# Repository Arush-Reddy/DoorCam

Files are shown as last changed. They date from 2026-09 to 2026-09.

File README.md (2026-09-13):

# DoorCam: Edge-AI Smart Video Doorbell System









An autonomous, enterprise-grade smart video doorbell and surveillance system engineered from the silicon up. DoorCam pairs an **ESP32-CAM (AI-Thinker with OV3660 3MP sensor)** edge device with a multi-threaded Python cloud backend, local **128-dimensional deep metric facial recognition**, and an installable **Progressive Web App (PWA)** featuring **24/7 on-demand live cloud streaming**, **sub-2-second instant doorbell alerting**, and zero-refresh real-time synchronization.

> 🔒 **Private & Self-Hosted:** Designed for deployment on private cloud containers (Docker / Render) or home local servers with zero open inbound firewall ports.  
> Built as an end-to-end hardware, firmware, and software engineering system demonstrating embedded C++/FreeRTOS programming, low-latency socket networking, asynchronous machine learning pipelines, and modern web engineering.

---

## 📸 System Architecture

```mermaid
sequenceDiagram
    autonumber
    actor Visitor
    actor Owner as Homeowner (Phone / PWA)
    participant ESP as ESP32-CAM (Edge)
    participant Cloud as Cloud Server (Flask)
    participant AI as Face AI Worker (dlib)
    participant Push as Mobile Push (ntfy)

    Note over Owner,Cloud: Workflow A - 24/7 On-Demand Live Streaming
    Owner->>Cloud: Tap Watch Live Stream
    Cloud->>Cloud: Arm stream demand flag (60s safety timeout)
    ESP->>Cloud: Polls GET /api/stream_cmd (every 1.5s in standby)
    Cloud-->>ESP: Stream command active (true)
    ESP->>Cloud: Push live MJPEG frames (13-15 FPS)
    Cloud-->>Owner: Multiplex live feed to connected devices
    Owner->>Cloud: Tap Stop Stream
    Cloud-->>ESP: Demand cleared - ESP returns to standby

    Note over Visitor,Owner: Workflow B - Physical Doorbell Ring
    Visitor->>ESP: Press Doorbell Button (GPIO 14 to GND)
    ESP->>ESP: Hardware Debounce Filter (40ms) + Capture Photo
    ESP->>Cloud: POST /visitor with photo snapshot
    Note over Cloud: Immediate ACK under 10ms (Zero blocking)
    Cloud-->>Owner: Broadcast SSE event - Doorbell Ringing
    Owner-->>Owner: Play Web Audio Chime + Device Vibration
    Cloud-->>ESP: HTTP 200 OK - ESP begins 30s live stream
    Cloud->>AI: Dispatch snapshot to background worker
    AI->>AI: Compute HOG and 128D ResNet Embeddings
    AI-->>Cloud: Update database with recognized identity
    Cloud-->>Owner: Broadcast SSE event - Name Resolved (Arush)
    Cloud-->>Push: Dispatch mobile push notification with photo
```

---

## ⚡ Key Engineering Highlights & Innovations

### 1. 📹 24/7 On-Demand Live Cloud Streaming (Global 4G/5G/Wi-Fi)
- **Zero Open Ingress Ports**: The ESP32-CAM operates safely behind standard residential NAT without requiring port forwarding. It polls `GET /api/stream_cmd` every 1.5s while idling in a low-power, cool-running standby state.
- **Instant Cloud Spin-up**: When the homeowner taps **"Watch Live Stream"** in the app, the cloud activates a demand token. On the next poll cycle, the ESP32-CAM seamlessly transitions into high-throughput socket streaming, delivering smooth **13–15 FPS live MJPEG video**.
- **Bandwidth Safety Guard**: To prevent unexpected data exhaustion on cloud platforms (e.g. Render's 100 GB/month quota), each session includes an automatic **60-second countdown safety timeout**, or can be manually stopped with 1 tap.
- **In-Flight Frame Drain Guard**: Clicking "Stop" activates a 4.5-second frame drain barrier to cleanly ignore any delayed network packets and prevent UI stutter.

### 2. 🔔 Physical Doorbell Button Priority & Stream Interrupt
- **Hardware Circuitry**: A physical tactile pushbutton on **GPIO 14** configured with internal pull-up and a 40ms software debounce filter.
- **Ring Priority**:
  - **From Standby**: Captures an immediate HD visitor snapshot, pushes to `/visitor`, triggers an instant chime alert, and automatically extends into a 30-second live cloud stream so the owner can converse or monitor in real time.
  - **During Active Streaming**: An in-stream interrupt detects the button press on GPIO 14, immediately records the visitor event, and seamlessly refreshes the stream timer by +30 seconds without dropping frames.

### 3. ⚡ Sub-2-Second Instant Chime Alerting (Asynchronous Neural Inference)
- **The Challenge**: Running heavy convolutional face detection (`dlib` HOG + 128-dimensional ResNet-34 metric learning) synchronously on a CPU takes 300–600 ms. In cloud environments, waiting for inference before responding caused a 6–7 second delay between the visitor pressing the button and the homeowner's phone chiming.
- **The Solution**: The server immediately acknowledges `/visitor`, broadcasts a real-time event (`"Doorbell Ringing..."`) via Server-Sent Events (SSE), and dispatches inference to a background worker thread.
  - **Chime Latency**: The browser/phone chimes and vibrates within **~1.8–2.0 seconds** of the physical button press.
  - **Dynamic Name Resolution**: When the AI worker finishes identifying the face, it pushes an in-place `visitor_update` event that dynamically replaces the card title with the recognized name without re-triggering the chime audio.

### 4. 🧠 128-Dimensional Biometric Facial Recognition
- **Engine**: Powered by `dlib`'s state-of-the-art Deep Residual Network (ResNet-34) trained on millions of facial landmarks.
- **Metric Matching**: Generates a 128-float biometric vector per detected face and computes Euclidean distance against enrolled reference encodings in `face_db/encodings.pkl`.
- **Confidence Calibration**: Uses a strict classification threshold (`0.54`) to eliminate false positives, tagging unknown visitors as `Unknown Visitor` while instantly recognizing enrolled family members.

### 5. 🔄 Zero-Refresh Real-Time Live Sync & Mobile PWA
- **Hybrid SSE + High-Frequency Polling**: Combines persistent Server-Sent Events (`/api/events/stream`) for sub-millisecond push delivery with a 1.5-second `/api/live_state` heartbeat for rock-solid fault tolerance.
- **Web Audio API Synthesizer**: Generates a 2-tone melodic doorbell chime (*Ding* at 659.25 Hz E5 $\rightarrow$ *Dong* at 523.25 Hz C5) natively in browser memory without requiring external audio asset downloads.
- **Screen Wake Lock API**: Automatically invokes `navigator.wakeLock.request('screen')` during live stream viewing to keep the smartphone display awake while monitoring the doorstep.
- **Dynamic Frame Fallback**: If an MJPEG socket stalls due to cellular network switching, the frontend seamlessly falls back to 120ms single-frame memory polling (`/api/latest_frame`).

### 6. 🕒 Local Timezone Display & 1-Tap Feed Purge
- **Timezone Standardization**: Server records timestamps in Indian Standard Time (IST, UTC+5:30) using `datetime.timezone`. The frontend's dynamic `formatDisplayTime` parser automatically formats both legacy UTC and local timestamps into clean, human-readable strings (e.g. `Sep 13, 12:47:15 PM`).
- **Real-Time Feed Clearing (`POST /api/feed/clear`)**: A dedicated **`[ 🗑️ Clear ]`** button with confirmation prompt safely purges the SQLite `visits` database table. The server broadcasts a `feed_cleared` SSE event, instantly emptying the timeline and updating event counters across all open devices without requiring a browser reload.

### 7. 🛡️ PIR Motion Sensor Cloud Toggle
- Software-controlled toggle via `POST /api/pir/toggle` allows the homeowner to enable or disable HC-SR501 PIR thermal motion alerts directly from the UI, preventing nuisance notifications caused by pets, swaying trees, or passing street traffic.

---

## 📊 Benchmark & Performance Metrics

| Metric | Measured Value | Significance |
| :--- | :--- | :--- |
| **Physical Button Debounce** | **40 ms** | Clean active-LOW transition with zero false double-triggers |
| **Doorbell Trigger Latency** | **< 10 ms** | Server receives and broadcasts event before edge ACK completes |
| **End-to-End Phone Chime** | **~1.8 s** | Total time from physical press to phone chime & vibration over cloud |
| **On-Demand Stream Start** | **1.2 – 1.8 s** | Time from "Watch Live" tap to active video rendering |
| **Stream Frame Rate** | **13 – 15 FPS** | Fluid MJPEG video over standard residential Wi-Fi & 4G/5G |
| **Frame Bandwidth** | **~12 – 15 KB** | Optimized JPEG quality index (`12`) balancing clarity and throughput |
| **Face Recognition Time** | **~280 ms** | Multi-threaded background dlib ResNet-34 inference |
| **Mobile Push Notification** | **< 1.0 s** | Rich push with snapshot delivered to phone lock screen via `ntfy.sh` |
| **Camera Watchdog Recovery** | **~1.5 s** | Automated hardware reset (`ESP.restart()`) on consecutive frame drops |

---

## 🛠️ Hardware Bill of Materials (BOM) & Pinout

| Component | Specification | Function |
| :--- | :--- | :--- |
| **MCU** | ESP32-D0WD-V3 (AI-Thinker module, 4MB PSRAM) | Edge controller and camera driver |
| **Camera Sensor** | Omnivision OV3660 (3.0 Megapixel) | Optical image sensor with hardware ISP |
| **Programmer** | ESP32-CAM-MB Shield (or ESP32-S3 UART Bridge) | Serial flashing and 5V USB power regulation |
| **Motion Sensor** | HC-SR501 Passive Infrared (PIR) | Thermal motion detection |
| **Doorbell Button** | SPST Tactile Push Button | Physical visitor trigger (Active LOW) |
| **LEDs** | GPIO 4 (Flash, 1W) / GPIO 33 (Status, Red) | Night illumination and boot diagnostics |

### Edge Pin Mapping
```
ESP32-CAM Pin     Peripheral Connection
-----------------------------------------------------------
GPIO 14   ------> Doorbell Push Button (Active LOW with internal PULLUP)
GPIO 13   ------> PIR Motion Sensor OUT (PULLDOWN)
GPIO 4    ------> Onboard High-Power Flash LED
GPIO 33   ------> Onboard Red Status LED (Active LOW)
GPIO 32   ------> OV3660 Power Down (PWDN, Active HIGH)
GPIO 0    ------> Bootloader Flashing Mode (Short to GND to Flash)
5V / GND  ------> Regulated 5V 2A Power Source
```

---

## 📡 REST & Real-Time API Reference

| Endpoint | Method | Description |
| :--- | :--- | :--- |
| `/` | `GET` | CCTV Security Dashboard & Progressive Web App interface |
| `/video_feed` | `GET` | Live multi-client MJPEG video stream (`multipart/x-mixed-replace`) |
| `/api/latest_frame` | `GET` | Returns the single most recent JPEG frame from server memory |
| `/api/events/stream` | `GET` | Server-Sent Events (SSE) real-time event pipeline |
| `/api/live_state` | `GET` | Live system state (stream active, FPS, remaining time, latest visit, PIR state) |
| `/api/stream/start` | `POST` | Demands live cloud streaming for 60 seconds |
| `/api/stream/stop` | `POST` | Terminates active live streaming and returns camera to standby |
| `/api/stream_cmd` | `GET` | Polled by ESP32 edge device (`{"stream": true/false}`) |
| `/api/stream_push` | `POST` | Ingestion endpoint where ESP32 pushes live JPEG frames |
| `/visitor` | `POST` | Trigger endpoint called on button ring/motion with snapshot attachment |
| `/api/feed/clear` | `POST` | Purges all visitor log records and broadcasts `feed_cleared` event |
| `/api/pir/toggle` | `POST` | Toggles PIR motion sensor alert evaluation on/off |
| `/api/diagnostics` | `GET` | Health check endpoint reporting Python, OpenCV, dlib, and face models |

---

## 🚀 Deployment & Getting Started

### 1. Cloud Deployment (Render.com + Docker)
The project includes a production-ready `Dockerfile` pre-configured with Python 3.11, CMake, dlib, and `face_recognition`.
1. Fork or push this repository to your GitHub account.
2. Link your repository to **[Render.com](https://render.com/)** as a **Web Service**.
3. Set Environment: **Docker**.
4. Set optional environment variables in Render Dashboard:
   - `BASE_DIR=/app`
   - `NTFY_TOPIC=arush-doorcam-cctv` (or your custom topic name)
5. Render builds the container and serves your application at `https://<your-subdomain>.onrender.com`.

### 2. Local Development Setup
```bash
git clone https://github.com/Arush-Reddy/DoorCam.git
cd DoorCam

# Create and activate virtual environment
python -m venv venv
venv\Scripts\activate  # Windows
source venv/bin/activate  # Linux/macOS

# Install dependencies
pip install -r requirements.txt

# Run server locally
python doorbell_server.py
```

### 3. Enrolling Known Faces
1. Place portrait photos (`.jpg` or `.png`) of individuals inside `known_faces/`:
   ```text
   known_faces/
   ├── Arush.jpg
   └── Mom.jpg
   ```
2. Run the offline facial embedding generator:
   ```bash
   python face_db/encode_faces.py
   ```
   This generates `face_db/encodings.pkl`, which is loaded into server memory on startup.

### 4. Flashing Firmware to ESP32-CAM
1. Open `firmware/doorbell_cam/doorbell_cam.ino` in Arduino IDE.
2. Select Board: **AI Thinker ESP32-CAM** | Partition: **Huge APP (3MB No OTA/1MB SPIFFS)**.
3. Export compiled binary (`Ctrl + Alt + S` in Arduino IDE).
4. Short **IO0 to GND** on the ESP32-CAM and plug into USB (or mount on ESP32-CAM-MB shield).
5. Flash using the high-speed flasher:
   ```powershell
   python firmware/fast_flash.py
   ```
6. Disconnect **IO0 from GND** and press the **RST** button.

---

## 🔒 Security & Privacy Architecture

- **Self-Hosted Biometric Privacy**: Biometric facial recognition models and feature vectors execute entirely within your private container or local server. No private facial embeddings are ever uploaded to third-party proprietary clouds.
- **Zero Inbound NAT Openings**: Remote streaming operates via outbound long-polling and socket pushes—no risky port forwarding or firewall exceptions required.
- **Encrypted Global Ingress**: All mobile dashboard sessions, live MJPEG feeds, and push communications run over TLS 1.3 encryption (HTTPS/WSS).
- **Zero Subscription Fees**: Built entirely on self-hosted open-source software and open protocols.

---

## 📄 License

This project is licensed under the MIT License — see the [LICENSE](LICENSE) file for details.

---

## 👤 Author

**Arush Reddy**  
- **GitHub:** [@Arush-Reddy](https://github.com/Arush-Reddy)  
- **Project:** [DoorCam — Edge-AI Smart Video Doorbell System](https://github.com/Arush-Reddy/DoorCam)

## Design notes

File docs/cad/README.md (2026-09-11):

# 3D Printable DoorCam Enclosure (Robu.in Ready)

This directory contains the production-grade CAD designs, binary 3D printable `.stl` models, and visual renders for the **DoorCam Smart Doorbell Enclosure**.

Engineered specifically for the **5x7cm Double-Sided FR-4 Perfboard**, **AI-Thinker ESP32-CAM**, **HC-SR501 PIR sensor**, **16mm tactile push button**, and **Type-C 16-pin USB breakout**.

---

## 📦 Production STL Files for 3D Printing

Both files are pre-oriented flat on the build plate (`Z = 0`), watertight, manifold, and require **zero support material**:

| Part | File Link | Dimensions (mm) | Triangles | Format | Print Orientation |
| :--- | :--- | :--- | :--- | :--- | :--- |
| **Front Shell** | [`doorbell_front.stl`](doorbell_front.stl) | `58.8 x 124.8 x 13.0` | 3,808 | Binary STL | Flat face on bed |
| **Back Shell** | [`doorbell_back.stl`](doorbell_back.stl) | `58.8 x 124.8 x 15.8` | 3,104 | Binary STL | Wall face on bed |

*(ASCII versions are also preserved at [`doorbell_front_ascii.stl`](doorbell_front_ascii.stl) and [`doorbell_back_ascii.stl`](doorbell_back_ascii.stl) for text inspection).*

---

## 🎨 Visual 3D Renders

| Front Shell Interior | Back Wall Mount Interior | Full Assembled Unit |
| :---: | :---: | :---: |
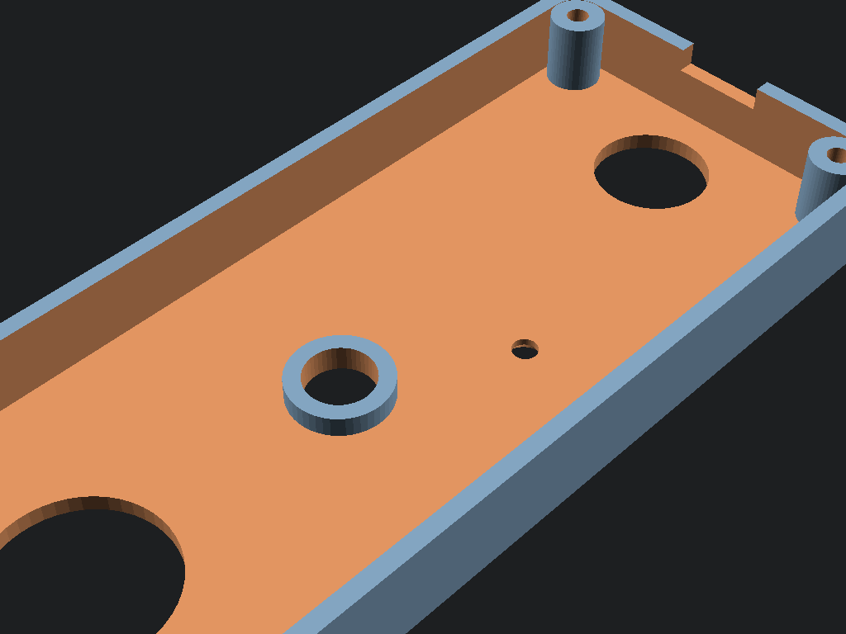
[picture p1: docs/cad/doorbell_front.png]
Front Shell
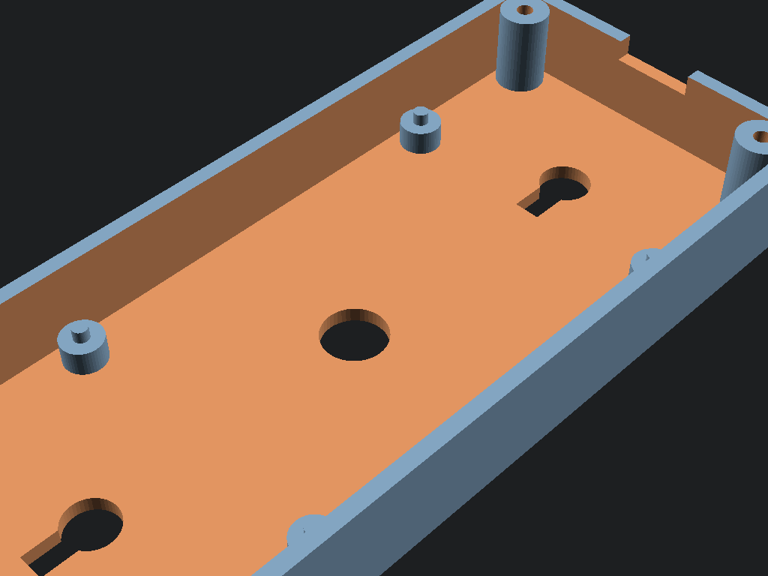
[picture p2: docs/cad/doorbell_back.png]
Back Shell
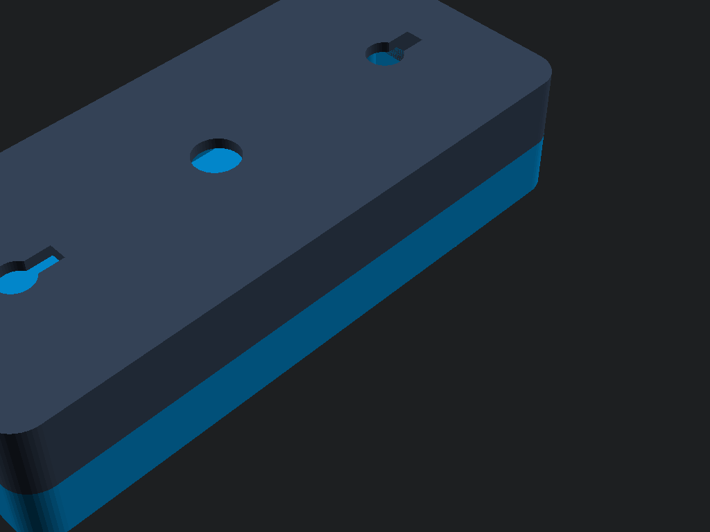
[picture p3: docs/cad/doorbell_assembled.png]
Assembled DoorCam
|  |  |  |

---

## 📐 Enclosure Technical Specifications

```
             Front Faceplate                            Side Cross-Section
     +------------------------------+                     +------------+
     |   [O] M3        [O] M3       |                     |            |
     |                              |                     |            |
     |          ( [CAM] )           | <-- 9.5mm Lens      |   FRONT    | 13.0 mm
     |                              |     Chamfer Bezel   |   SHELL    |
     |           ( PIR )            | <-- 23.5mm Dome     |            |
     |                              |     Cutout          +------------+ <-- Parting Line
     |                              |                     |            |
     |           [  O  ]            | <-- 16mm Button     |    BACK    | 15.8 mm
     |                              |     Aperture        |   SHELL    |
     |            ====              | <-- Type-C USB      | (Wall Mnt) |
     |   [O] M3        [O] M3       |                     |            |
     +------------------------------+                     +------------+
                 58.8 mm                                      28.8 mm
```

- **Outer Dimensions:** `58.8 mm (W) x 124.8 mm (L) x 28.8 mm (H)`
- **Internal Cavity:** `54.0 mm x 120.0 mm x 24.0 mm`
  - Perfectly accommodates standard 50mm x 70mm perfboard with 2mm perimeter clearance.
  - Accommodates stacked ESP32-CAM, female headers, 100µF capacitor, and wiring.
- **Wall Thickness:** `2.4 mm` (heavy-duty structural rigidity for outdoor environments).
- **Corner Fillets:** `6.5 mm` rounded radius.
- **Fasteners:** 4x M3 countersunk screws (`3.2 mm` clearance in front shell, `2.7 mm` self-tapping pilot holes in back shell).
- **Mounting:** 2x Wall screw keyholes (`8mm` head entry, `4.2mm` shank slot) + `10mm` center wire pass-through hole.
- **PCB Standoffs:** 4x built-in `4.0 mm` height support pillars in back shell.

---

## 🚀 How to Order on Robu.in 3D Printing Service

1. Visit [Robu.in Online 3D Printing Service](https://robu.in/product-category/3d-printing-services/).
2. Click **Instant Quote / Upload CAD Files**.
3. Upload both files:
   - `docs/cad/doorbell_front.stl`
   - `docs/cad/doorbell_back.stl`
4. Select the following print parameters:
   - **Technology:** **FDM (Fused Deposition Modeling)**
   - **Material:** **Black PETG** (Recommended for outdoor UV & weather resistance) or **PLA+**
   - **Infill:** **20% – 25%** (Gyroid or Grid pattern)
   - **Layer Height:** **0.20 mm** (Standard / Quality)
   - **Supports:** **None (Zero supports needed)**
5. Submit the order for delivery!

---

## 🛠️ Recompiling from Source

If you wish to modify dimensions:
1. Open [`doorbell_case.scad`](doorbell_case.scad) in OpenSCAD.
2. Edit dimensions in the header.
3. Run the automated build script:
   ```bash
   py -3.12 docs/cad/build_stls.py
   ```
   This compiles both STLs and updates preview renders automatically.

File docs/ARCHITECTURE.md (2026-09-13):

# System Architecture & Technical Deep Dive

This document details the hardware, firmware, and software engineering design decisions behind **DoorCam**, an open-source AI-powered smart video doorbell system.

---

## 1. System Block Diagram

```mermaid
graph TB
    subgraph EdgeDevice ["Edge Device: ESP32-CAM (AI Thinker + OV3660)"]
        OV[OV3660 3MP Sensor] -->|DMA / I2S Bus| CAM_BUF[2x Framebuffers in PSRAM]
        CAM_BUF -->|MJPEG Chunking| HTTP_SRV[esp_http_server Task: Port 81]
        BTN[Push Button GPIO 14] -->|Hardware Debounce| TRIG[Event Dispatcher]
        PIR[PIR HC-SR501 GPIO 13] -->|Active-High Interrupt| TRIG
        TRIG -->|HTTP POST ~5ms 0-byte| NET_OUT[WiFi Radio 2.4GHz]
    end

    subgraph HostServer ["Host Server: Python Flask Backend (Port 5000)"]
        NET_OUT -.->|HTTP POST /visitor| ROUTE_VIS[/visitor Endpoint]
        HTTP_SRV -.->|Persistent Single Socket| RELAY[CameraStreamRelay Worker Thread]
        RELAY -->|Latest Frame Buffer| RAM_BUF[(In-Memory JPEG Buffer)]
        
        ROUTE_VIS -->|Instant Snapshot Read| RAM_BUF
        ROUTE_VIS -->|Save to Disk| DISK[visitors/YYYY-MM-DD/]
        DISK -->|Image Array| FACE_AI[Face Recognition Engine: dlib / HOG]
        FACE_AI -->|Match Distance & ID| DB[(SQLite: visitors.db)]
        
        DB -->|Broadcast Visitor Event| SSE[Server-Sent Events: /api/events/stream]
        ROUTE_VIS -->|Dispatch Rich Alert| NTFY_CLIENT[ntfy.sh REST API]
    end

    subgraph Clients ["Client Ecosystem"]
        RAM_BUF -->|Deduplicated Stream| WEB_FEED[/video_feed: ~30 FPS]
        WEB_FEED --> PWA[Mobile / Desktop PWA Browser]
        SSE --> PWA
        NTFY_CLIENT --> MOBILE[Mobile Lock Screen Push Notifications]
    end
```

---

## 2. Firmware Architecture & Hardware Constraints

### A. DMA Buffer Allocation & Race Condition Avoidance
The ESP32-CAM utilizes an **OV3660 3-Megapixel CMOS sensor** communicating over a 10-line parallel interface (D0–D7, VSYNC, HREF, PCLK) using Direct Memory Access (DMA).

- **PSRAM Dual Buffering (`fb_count = 2`)**: The ESP32's 4MB external PSRAM is configured to allocate two framebuffers (`FRAMESIZE_VGA` at `640x480`).
- **Single-Consumer Guarantee**: To prevent catastrophic DMA starvation (where concurrent FreeRTOS tasks call `esp_camera_fb_get()` and exhaust buffers, locking up the I2S DMA FIFO), firmware enforces strict separation of concerns:
  - The `stream_handler` running on the `httpd` worker task is the **sole consumer** of `esp_camera_fb_get()`.
  - Doorbell push button and PIR sensor events **never** attempt camera capture on the edge device. Instead, they transmit a 0-byte trigger signal to the host server in ~5 ms.

### B. Self-Healing Camera Watchdog
Hardware sensors exposed to long jumper wires and electrical noise can experience SCCB/I2C bus drops or DMA timeouts. 
- Firmware implements consecutive-failure tracking in `stream_handler`:
  - Transient single-frame drops yield for 40 ms and retry without aborting the HTTP connection.
  - If 15 consecutive capture attempts fail, the firmware triggers an automated hardware reboot via `ESP.restart()`, bringing the camera back online within 1.5 seconds without requiring physical intervention.

---

## 3. Zero-Payload Event Triggering

Traditional IoT camera sketches attempt to capture high-resolution photos and upload multipart payloads (60–100 KB) when an event occurs. On single-radio 2.4 GHz ESP32 chips, doing this while simultaneously serving a video stream causes:
1. Wi-Fi packet drops and LwIP TCP buffer exhaustion.
2. Frame rate degradation to 0 FPS (freezing).
3. Simultaneous DMA buffer acquisition collisions.

### Zero-Payload Sequence Diagram
```mermaid
sequenceDiagram
    autonumber
    actor Visitor
    participant ESP as ESP32-CAM (Firmware)
    participant Relay as Python Stream Relay
    participant Host as Python /visitor Route
    participant Phone as Mobile Device (ntfy)

    Note over ESP,Relay: Continuous 25-30 FPS MJPEG Stream active on Port 81
    Visitor->>ESP: Presses Doorbell Button (GPIO 14 pulled LOW)
    ESP->>ESP: Hardware Debounce Filter (40 ms check)
    ESP->>Host: POST /visitor?trigger=BUTTON (Content-Length: 0)
    Note over ESP: Latency: ~5ms. Stream never pauses!
    Host->>Relay: Extract latest JPEG from memory buffer
    Host->>Host: Save JPEG to disk & run Face AI
    Host-->>Phone: Dispatch Push Notification with Photo Attachment
    Host-->>ESP: HTTP 200 OK
    ESP->>ESP: Blink onboard status LED
```

---

## 4. Software Backend & Stream Multiplexing

### A. CameraStreamRelay Architecture
The ESP32 `httpd` component is constrained to 4 concurrent sockets and single-threaded request handlers. Directly connecting multiple mobile phones and browser tabs to the camera locks up the device.

The Python server solves this using the **`CameraStreamRelay`** daemon:
- Maintains **exactly one** persistent HTTP connection to `http://<ESP32_IP>:81/`.
- Reads chunks from the HTTP stream, searches for JPEG boundary markers (`0xFF, 0xD8` for SOI and `0xFF, 0xD9` for EOI), and isolates complete frames into thread-safe memory.
- Protects the latest frame with a `threading.Lock()` and tracks the arrival timestamp `last_frame_time`.

### B. Frame Deduplication in `/video_feed`
Naive streaming relays yield the latest frame in a timed loop (e.g. every 40 ms). If the camera experiences a transient 100 ms Wi-Fi delay, the server sends duplicate frames, flooding client decoders.

DoorCam implements **timestamp-based frame deduplication**:
```python
last_sent_time = 0
while True:
    with camera_relay.lock:
        frame = camera_relay.latest_frame
        frame_time = camera_relay.last_frame_time
    if frame and frame_time != last_sent_time:
        last_sent_time = frame_time
        yield (b"--boundary\r\nContent-Type: image/jpeg\r\n\r\n" + frame + b"\r\n")
    time.sleep(0.01)
```
This guarantees clients receive only new, unique frames, minimizing client decode overhead and network utilization.

---

## 5. Facial Recognition Pipeline

```mermaid
flowchart LR
    A[Raw JPEG Frame] --> B[HOG Face Detection]
    B --> C[68 Face Landmarks]
    C --> D[128D Deep Metric Embedding]
    D --> E{Euclidean Distance <= 0.54?}
    E -- Yes --> F[Known Individual Label]
    E -- No --> G[Unknown Visitor]
```

1. **Detection**: Histogram of Oriented Gradients (HOG) algorithm identifies face bounding boxes.
2. **Alignment**: 68 facial landmarks are computed using dlib's shape predictor.
3. **Embedding**: A deep ResNet neural network maps the aligned face into a **128-dimensional hypersphere embedding**.
4. **Classification**: Vector distance between the input face embedding and the pre-computed known face database is calculated via Euclidean metric:
   $$d = \sqrt{\sum_{i=1}^{128} (x_i - y_i)^2}$$
5. **Threshold**: A calibrated distance threshold of `0.54` provides an optimal balance between false acceptance and false rejection on doorway perspectives.

---

## 6. Database Schema

DoorCam logs all visitor interactions to a lightweight SQLite database (`visitors.db`):

```sql
CREATE TABLE IF NOT EXISTS visits (
    id INTEGER PRIMARY KEY AUTOINCREMENT,
    timestamp DATETIME DEFAULT CURRENT_TIMESTAMP,
    name TEXT NOT NULL,
    photo_path TEXT NOT NULL,
    trigger_source TEXT NOT NULL,  -- 'BUTTON' or 'PIR'
    confidence REAL                -- Distance metric (lower is more confident)
);

CREATE INDEX IF NOT EXISTS idx_visits_timestamp ON visits(timestamp);
```

---

## 7. On-Demand Cloud Streaming & Bandwidth Safety Engine

To operate within cloud resource constraints (such as Render's 100 GB/month bandwidth limit) while preventing continuous heat generation on the ESP32-CAM, DoorCam employs an **on-demand signaling protocol**:

```mermaid
sequenceDiagram
    participant User as Mobile App / PWA
    participant Server as Flask Server (/api)
    participant Edge as ESP32-CAM

    Note over Edge,Server: Standby Mode: Low power, 0 FPS, polling /api/stream_cmd every 1.5s
    User->>Server: POST /api/stream/start {duration: 60}
    Server->>Server: Arm demand timer (expires in 60s)
    Edge->>Server: GET /api/stream_cmd
    Server-->>Edge: {"stream": true}
    Note over Edge: Edge spins up WiFiClient socket
    loop 13-15 FPS Live Stream
        Edge->>Server: POST /api/stream_push (JPEG frame binary)
        Server->>User: /video_feed (MJPEG multipart)
    end
    User->>Server: POST /api/stream/stop OR Timeout (60s)
    Server->>Server: Demand token cleared
    Edge->>Server: GET /api/stream_cmd
    Server-->>Edge: {"stream": false}
    Note over Edge: Edge terminates TCP push socket & returns to cool standby
```

### In-Flight Frame Drain Guard
When a user clicks **Stop Stream**, delayed network frames in transit over cellular data can arrive after the client has switched to snapshot view. The client and server enforce a 4.5-second frame drain barrier that suppresses stale frames, ensuring a clean freeze-frame snapshot state.

---

## 8. Asynchronous Biometric Inference & Sub-2s Chime Pipeline

Synchronous execution of deep convolutional neural networks (`dlib` HOG detection and ResNet-34 landmark embedding) introduces a 300–600 ms compute latency. Over WAN connections, this resulted in a 6–7 second delay between a physical button press and the homeowner's smartphone chiming.

### Decoupled Worker Thread Architecture
```mermaid
flowchart TD
    A[Button Pressed GPIO 14] -->|POST /visitor| B[Flask Request Handler]
    B -->|Broadcast Instant Alert| C[SSE: 'Doorbell Ringing...']
    C -->|Web Audio API| D[Phone Chimes in ~1.8s + Vibrates]
    B -->|HTTP 200 OK| E[ESP32 Begins 30s Stream]
    B -->|Enqueue Snapshot| F[Background AI Daemon Thread]
    F -->|dlib HOG & ResNet| G[Identify Face: 'Arush' / Unknown]
    G -->|Update DB Record| H[visitors.db]
    G -->|Broadcast In-Place Update| I[SSE: 'visitor_update']
    I -->|Smooth DOM Replacement| J[Card Name Updates Without Re-chiming]
```

This decoupled architecture guarantees **sub-2-second end-to-end chime alerts** while preserving 100% facial recognition accuracy.

---

## 9. Local Timezone Display & Real-Time Feed Purging

### Timezone Normalization
- Server instances (e.g. Render Linux containers running in UTC) record timestamps using `LOCAL_TIMEZONE = datetime.timezone(datetime.timedelta(hours=5, minutes=30))` (IST).
- The client-side `formatDisplayTime(rawTs)` engine automatically parses legacy UTC entries and current timestamps, formatting them cleanly as `Sep 13, 12:47:15 PM`.

### Real-Time Feed Clearing
- Triggering `POST /api/feed/clear` executes `DELETE FROM visits` on the SQLite database.
- The server broadcasts a `feed_cleared` event across the Server-Sent Events pipeline.
- All active browser tabs and mobile devices synchronously clear their DOM timelines, reset the event counter to `0 events`, and display the empty-state illustration without requiring a manual page refresh.

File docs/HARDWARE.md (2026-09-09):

# Hardware & Wiring Specifications

This guide covers component specifications, electrical schematics, pin mappings, and hardware flashing workflows for the **DoorCam** edge device.

---

## 1. Hardware Bill of Materials (BOM)

| Component | Part / Model | Purpose | Operating Voltage |
| :--- | :--- | :--- | :--- |
| **Edge Microcontroller** | ESP32-CAM (AI-Thinker) | Dual-core 240MHz MCU with 4MB External PSRAM & Wi-Fi | 5.0V input (3.3V internal) |
| **Image Sensor** | OmniVision OV3660 | 3.0 Megapixel CMOS sensor with 68° FoV & hardware ISP | 3.3V / 1.5V Core |
| **Motion Detector** | HC-SR501 | Passive Infrared (PIR) thermal motion sensor | 4.5V – 12V (5V rail) |
| **Doorbell Button** | 12mm Tactile Push Button | Physical visitor trigger switch | 3.3V Logic |
| **Status / Flash LEDs** | Onboard SMD LEDs | GPIO 4 (1W Warm Flash), GPIO 33 (Red Activity LED) | 3.3V Logic |
| **Power Supply** | Micro-USB 5V 2.0A Adapter | Clean, regulated DC power source | 5.0V ± 0.25V |

---

## 2. Complete Wiring Schematic

```
                          +-------------------+
                          |    ESP32-CAM      |
                          |                   |
       +5V Supply --------| 5V                |
       GND        --------| GND               |
                          |                   |
    [PIR Sensor]          |                   |
       VCC    <-----------| 5V                |
       GND    <-----------| GND               |
       OUT    ----------->| GPIO 13 (INPUT)   |
                          |                   |
    [Doorbell Button]     |                   |
       Terminal 1 ------->| GPIO 14 (PULLUP)  |
       Terminal 2 ------->| GND               |
                          |                   |
    [OV3660 Camera]       |                   |
       24-Pin FPC Cable ->| 24-Pin Camera Slot|
                          +-------------------+
```

### Pinout Rationale & Design Considerations:
- **GPIO 14 (Doorbell Push Button):** Configured as `INPUT_PULLUP`. In idle state, the internal pull-up resistor holds the pin HIGH (3.3V). Depressing the button shorts the pin directly to GND (Active LOW), triggering the 40ms debounce state machine.
- **GPIO 13 (PIR Sensor):** Configured as `INPUT_PULLDOWN`. When the HC-SR501 detects infrared radiation, its digital output goes HIGH (3.3V). The pull-down resistor eliminates floating gate noise when the sensor is uncoupled.
- **GPIO 32 (Camera Power Down / PWDN):** Used by the firmware watchdog to physically power-cycle the OV3660 CMOS sensor during bootup and failure recovery.
- **GPIO 4 & 33:** Onboard LEDs. GPIO 4 drives the flash transistor (Active HIGH); GPIO 33 drives the small red indicator LED (Active LOW).

---

## 3. Programming & Flashing Methods

### Method 1: Using the ESP32-CAM-MB Shield (Standard)
The **ESP32-CAM-MB** daughterboard plugs directly into the back header pins of the ESP32-CAM:
1. Mount the ESP32-CAM on the MB shield (ensure the antenna aligns with the shield cut-out).
2. Plug a standard Micro-USB cable into the MB shield port.
3. The onboard CH340 / CP2102 chip automatically toggles DTR and RTS lines to enter bootloader mode without manual jumpers.
4. Select board **AI Thinker ESP32-CAM** in Arduino IDE or run `python firmware/fast_flash.py`.

---

### Method 2: Using an ESP32-S3 as a Serial Bridge (No FTDI Needed)
If a dedicated USB-to-UART FTDI programmer is unavailable, an auxiliary **ESP32-S3 board** can be scripted as an ultra-fast hardware UART passthrough bridge.

#### Bridge Wiring:
```
  ESP32-S3 Bridge                ESP32-CAM (Target)
-----------------------------------------------------------
  5V             --------------> 5V
  GND            --------------> GND
  GPIO 18 (S3 RX) <------------- U0T (ESP32-CAM TX)
  GPIO 17 (S3 TX) --------------> U0R (ESP32-CAM RX)
  GND            --------------> IO0 (Short to GND for flashing)
```

#### Flashing Workflow via S3 Bridge:
1. Connect **IO0 to GND** on the ESP32-CAM.
2. Press the **RST** button on the ESP32-CAM to place its boot ROM in UART download mode.
3. Execute `python firmware/fast_flash.py`:
   ```bash
   python firmware/fast_flash.py
   ```
4. Once flashed, **disconnect IO0 from GND** and press the **RST** button to start normal operation.

---

## 4. Optical Sensor Tuning (OV3660)

The **Omnivision OV3660** 3MP CMOS sensor delivers significantly higher dynamic range and low-light sensitivity than the legacy OV2640.

The firmware applies the following hardware ISP corrections upon successful boot:
```c
sensor_t * s = esp_camera_sensor_get();
if (s && s->id.PID == OV3660_PID) {
    s->set_vflip(s, 1);        // Correct inverted optical lens mount
    s->set_hmirror(s, 0);      // Horizontal mirror off
    s->set_brightness(s, 1);   // Boost contrast in doorstep shadow conditions
    s->set_saturation(s, -1);  // Normalize aggressive color saturation
}
```

---

## 5. Electrical Stability & Brownout Protection

The ESP32 Wi-Fi radio draws brief current spikes up to **350–450 mA** during transmission. If powered via long USB cables or inadequate 500mA PC ports, the supply voltage can drop below 2.7V, triggering the ESP32 internal brownout detector.

**Mitigation Measures:**
1. **Software:** Brownout detector disabled in `setup()` via:
   ```c
   WRITE_PERI_REG(RTC_CNTL_BROWN_OUT_REG, 0);
   ```
2. **Hardware:** Use a dedicated 5V 2A USB wall adapter. A 100μF – 470μF electrolytic capacitor placed across the 5V and GND pins of the ESP32-CAM absorbs transient RF current spikes.

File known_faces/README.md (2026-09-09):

# Known Faces Directory

Place photos of known family members, friends, or yourself here.

### Guidelines:
1. **Naming**: The filename without extension will be used as the person's name.
   - Example: `arush.jpg` -> Name: **Arush**
   - Example: `dad.png` -> Name: **Dad**
   - Example: `uncle_bob.jpg` -> Name: **Uncle Bob**

2. **Photo Quality**:
   - Clear, well-lit, frontal face photo.
   - Only ONE person per photo.
   - Neutral expression or natural smile.

3. **After adding or updating photos**:
   Run:
   ```powershell
   python face_db/encode_faces.py
   ```
   This will update `face_db/encodings.pkl`.

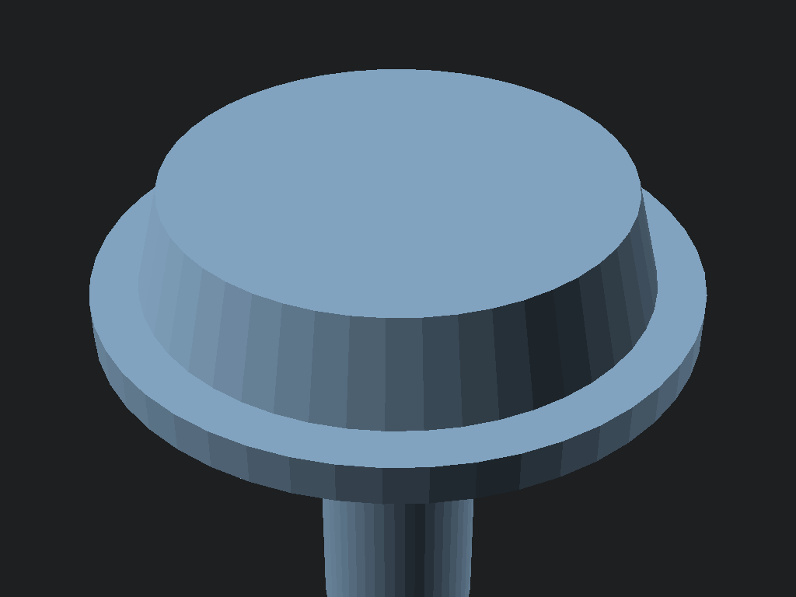
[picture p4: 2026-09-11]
docs/cad/doorbell_button.png

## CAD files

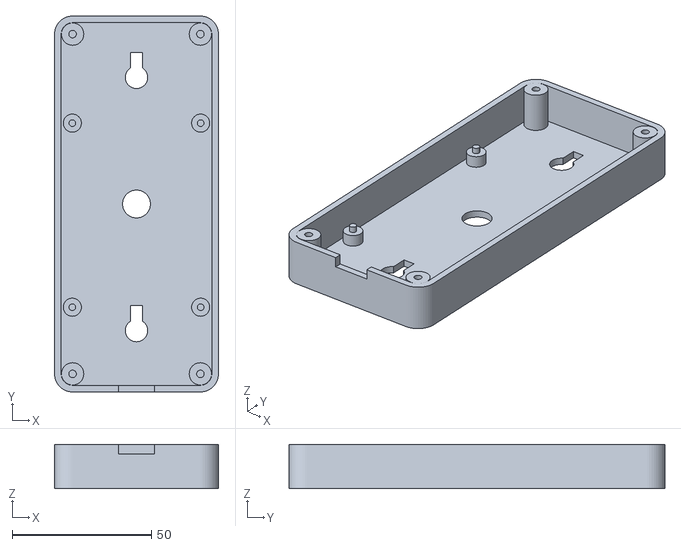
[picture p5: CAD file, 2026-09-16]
docs/cad/doorbell_back.stl
58.8 x 134.8 x 15.8

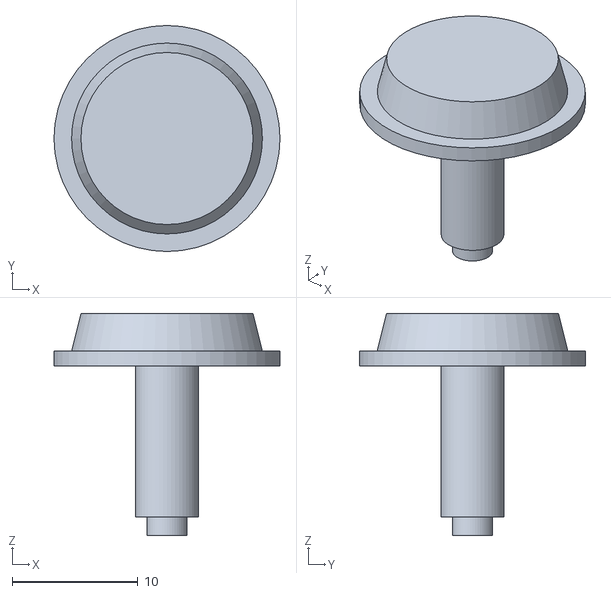
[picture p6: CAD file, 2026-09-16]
docs/cad/doorbell_button_ascii.stl
18.0 x 18.0 x 17.7

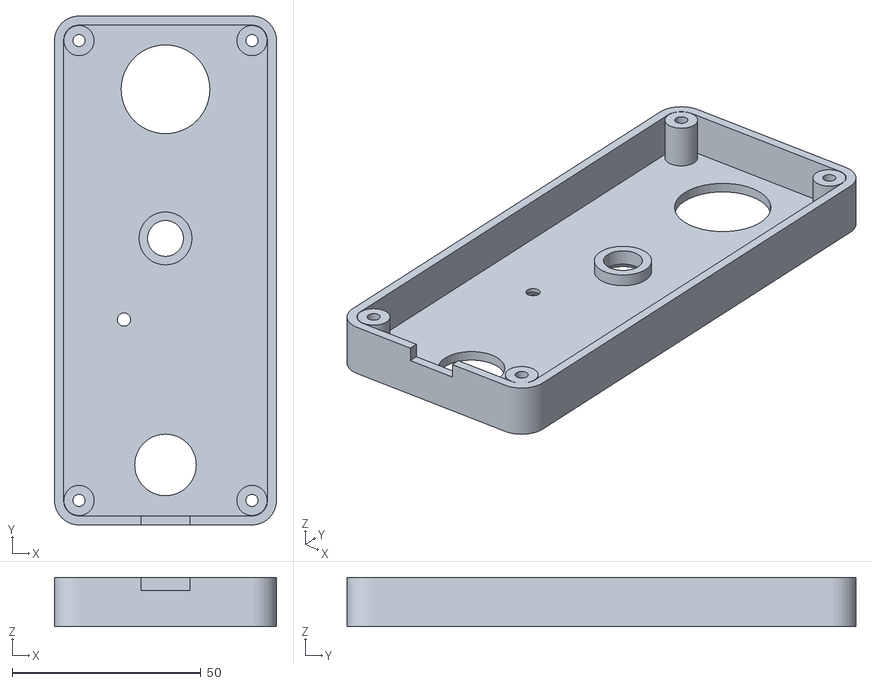
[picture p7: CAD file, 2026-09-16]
docs/cad/doorbell_front_ascii.stl
58.8 x 134.8 x 13.0

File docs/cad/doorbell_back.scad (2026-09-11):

// DoorCam Back Shell (Robu 3D Print Ready)
// Flat on build plate (Z=0, zero supports needed)
use <doorbell_case.scad>

$fn = 48;
back_shell();

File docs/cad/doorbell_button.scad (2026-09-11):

// DoorCam 16mm Tactile Button Plunger Cap
// Fits the 16mm front shell aperture and presses an internal 6x6mm tactile switch
$fn = 48;

cap_d     = 15.2;   // Outer button cap diameter (smooth slip fit in 16mm hole)
cap_h     = 3.0;    // Visible button face thickness
flange_d  = 18.0;   // Retaining flange (prevents button from falling out of front)
flange_h  = 1.2;    // Flange thickness
stem_d    = 5.0;    // Stem diameter pressing against the 6x6 tactile button
stem_len  = 12.0;   // Length extending to reach the PCB switch
nub_d     = 3.2;    // Actuator tip
nub_h     = 1.5;

union() {
    // 1. Chamfered tactile face (pokes through front hole)
    translate([0, 0, flange_h])
        cylinder(d1=cap_d, d2=cap_d - 1.5, h=cap_h);

    // 2. Retaining flange (rests inside the case against front wall)
    cylinder(d=flange_d, h=flange_h);

    // 3. Central plunger stem extending down to the 6x6mm switch
    translate([0, 0, -stem_len])
        cylinder(d=stem_d, h=stem_len);

    // 4. Contact nub that centers onto the tactile button
    translate([0, 0, -stem_len - nub_h])
        cylinder(d=nub_d, h=nub_h);
}

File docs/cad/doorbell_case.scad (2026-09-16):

// ====================================================================
// DoorCam v1.0 - Production 3D Printable Smart Doorbell Enclosure
// Precision engineered for: 
//   - 5x7cm Perfboard (50mm x 70mm)
//   - AI-Thinker ESP32-CAM (OV3660 / OV2640)
//   - HC-SR501 PIR Motion Sensor (23mm Fresnel dome)
//   - 6x6mm Tactile Button (via 3D Plunger) OR 16mm Panel Button
//   - Type-C 16-Pin USB Breakout Board
// Fully optimized for Robu.in / JLCPCB / Local 3D Print Services
// ====================================================================

$fn = 48; // Ultra-smooth curves for production quality

// --- PART SELECTOR ---
PART = "assembled"; // ["front", "back", "button", "assembled"]

// --- CORE DIMENSIONS (mm) ---
wall_thick   = 2.4;     // Sturdy outdoor wall thickness
inner_w      = 54.0;    // 50.0mm perfboard + 2mm margin per side
inner_l      = 130.0;   // 70mm perfboard + 34mm PIR cavity + 26mm button bay
inner_h      = 24.0;    // Internal cavity height for full component stack
fillet_r     = 6.5;     // Smooth ergonomic rounded outer corners

outer_w      = inner_w + wall_thick * 2; // 58.8 mm
outer_l      = inner_l + wall_thick * 2; // 134.8 mm (~13.5 cm)

split_z      = 13.0;    // Front shell height
back_depth   = inner_h - (split_z - wall_thick) + wall_thick; // 15.8 mm (Total height = 28.8 mm)

// --- SENSOR & APERTURE POSITIONS (from bottom inner wall) ---
// Based on exact eye-level physical ruler measurements:
pcb_offset_y = 26.0;    // Perfboard bottom edge rests at 26.0mm from bottom inner wall
cam_lens_d   = 9.5;     // OV3660 lens barrel diameter
cam_lens_y   = pcb_offset_y + 47.5; // 73.5 mm (EXACT match to user's 4.75cm physical eye measurement!)
pir_d        = 23.5;    // HC-SR501 Fresnel dome diameter
pir_y        = 113.0;   // Centered in top 34mm cavity (5.25mm clearance each side)
btn_d        = 16.3;    // 16.3mm slip-fit for M16 panel button (R13-507)
btn_y        = 13.5;    // Centered in bottom bay (5.35mm to wall, 4.35mm to PCB)
flash_led_x  = -11.0;   // Flash LED X offset from center (-11.0 = bottom-right when viewed from front face)
flash_led_y  = pcb_offset_y + 26.0; // 52.0 mm (EXACT match to user's 2.6cm physical eye measurement!)
flash_led_d  = 3.5;     // 3.5mm aperture for wide-angle flashlight illumination
usbc_w       = 13.0;    // USB-C clearance width
usbc_h       = 7.0;     // USB-C clearance height

screw_inset  = 6.5;     // Corner screw center from outer edge
boss_od      = 8.0;     // Screw boss outer diameter

// --- HELPER: ROUNDED BOX ---
module rounded_box(w, l, h, r) {
    hull() {
        translate([r, r, 0]) cylinder(r=r, h=h);
        translate([w-r, r, 0]) cylinder(r=r, h=h);
        translate([r, l-r, 0]) cylinder(r=r, h=h);
        translate([w-r, l-r, 0]) cylinder(r=r, h=h);
    }
}

// ====================================================================
// 1. FRONT SHELL (Outer face flat on bed at Z=0, zero supports needed!)
// ====================================================================
module front_shell() {
    difference() {
        // --- 1. SOLID POSITIVES ---
        union() {
            // Hollow Body Tray (Outer box minus cavity)
            difference() {
                rounded_box(outer_w, outer_l, split_z, fillet_r);
                translate([wall_thick, wall_thick, wall_thick])
                    rounded_box(inner_w, inner_l, split_z + 1, max(1, fillet_r - wall_thick));
            }

            // 4 Corner Screw Bosses (solid columns inside the tray)
            for (pos = [
                [screw_inset, screw_inset],
                [outer_w - screw_inset, screw_inset],
                [screw_inset, outer_l - screw_inset],
                [outer_w - screw_inset, outer_l - screw_inset]
            ]) {
                translate([pos[0], pos[1], wall_thick])
                    cylinder(d=boss_od, h=split_z - wall_thick);
            }

            // Camera Lens Rear Positioning Collar
            translate([outer_w/2, wall_thick + cam_lens_y, wall_thick])
                cylinder(d=cam_lens_d + 4.5, h=3.0);
        }

        // --- 2. NEGATIVE CUTOUTS ---

        // 1. Camera Lens Aperture
        translate([outer_w/2, wall_thick + cam_lens_y, -1])
            cylinder(d=cam_lens_d, h=wall_thick + 5.0);

        // 2. Protective Lens Chamfer Bezel (Angled sun/rain hood)
        translate([outer_w/2, wall_thick + cam_lens_y, -0.1])
            cylinder(d1=cam_lens_d + 3.6, d2=cam_lens_d, h=1.8);

        // 3. Status / Flash LED Light-pipe (3.5mm hole with wide-beam bezel)
        translate([outer_w/2 + flash_led_x, wall_thick + flash_led_y, -1])
            cylinder(d=flash_led_d, h=wall_thick + 2.0);
        translate([outer_w/2 + flash_led_x, wall_thick + flash_led_y, -0.1])
            cylinder(d1=flash_led_d + 2.0, d2=flash_led_d, h=1.5);

        // 4. HC-SR501 PIR Dome Aperture (23.5mm)
        translate([outer_w/2, wall_thick + pir_y, -1])
            cylinder(d=pir_d, h=wall_thick + 2.0);

        // 5. Doorbell Push Button Hole (16mm through outer wall & guide sleeve)
        translate([outer_w/2, wall_thick + btn_y, -1])
            cylinder(d=btn_d, h=wall_thick + 6.0);

        // 6. USB-C Port Notch (Top half at split line)
        translate([outer_w/2 - usbc_w/2, -1, split_z - usbc_h/2])
            cube([usbc_w, wall_thick + 2, usbc_h + 1]);

        // 7. Corner Screws (M3 Clearance = 3.2mm through outer wall & boss)
        for (pos = [
            [screw_inset, screw_inset],
            [outer_w - screw_inset, screw_inset],
            [screw_inset, outer_l - screw_inset],
            [outer_w - screw_inset, outer_l - screw_inset]
        ]) {
            // 3.2mm Clearance Hole
            translate([pos[0], pos[1], -1])
                cylinder(d=3.2, h=split_z + 2);

            // M3 Countersink Head on outer face (90-degree standard cone)
            translate([pos[0], pos[1], -0.1])
                cylinder(d1=6.4, d2=3.2, h=1.8);
        }
    }
}

// ====================================================================
// 2. BACK SHELL (Mounting face flat on bed at Z=0, zero supports needed!)
// ====================================================================
module back_shell() {
    difference() {
        // --- 1. SOLID POSITIVES ---
        union() {
            // Hollow Body Tray (Outer box minus cavity)
            difference() {
                rounded_box(outer_w, outer_l, back_depth, fillet_r);
                translate([wall_thick, wall_thick, wall_thick])
                    rounded_box(inner_w, inner_l, back_depth + 1, max(1, fillet_r - wall_thick));
            }

            // 4 Corner Screw Bosses (with M3 pilot holes)
            for (pos = [
                [screw_inset, screw_inset],
                [outer_w - screw_inset, screw_inset],
                [screw_inset, outer_l - screw_inset],
                [outer_w - screw_inset, outer_l - screw_inset]
            ]) {
                translate([pos[0], pos[1], wall_thick])
                    cylinder(d=boss_od, h=back_depth - wall_thick);
            }

            // 4 Perfboard Support Standoffs (4mm height, supports 50x70mm board)
            // Exactly aligned with user's physical measurement: 46.0mm (W) x 66.0mm (H)
            pcb_standoff_h = 4.0;
            hole_dx = 46.0;
            hole_dy = 66.0;
            board_margin_x = (50.0 - hole_dx) / 2; // 2.0mm
            board_margin_y = (70.0 - hole_dy) / 2; // 2.0mm
            board_start_x  = outer_w / 2 - 25.0;    // centered 50mm board
            for (p = [
                [board_start_x + board_margin_x, wall_thick + pcb_offset_y + board_margin_y],
                [board_start_x + 50.0 - board_margin_x, wall_thick + pcb_offset_y + board_margin_y],
                [board_start_x + board_margin_x, wall_thick + pcb_offset_y + 70.0 - board_margin_y],
                [board_start_x + 50.0 - board_margin_x, wall_thick + pcb_offset_y + 70.0 - board_margin_y]
            ]) {
                translate([p[0], p[1], wall_thick]) {
                    cylinder(d=6.5, h=pcb_standoff_h);
                    // 2.4mm locating pin (drops right into perfboard M3 corner holes for instant alignment!)
                    cylinder(d=2.4, h=pcb_standoff_h + 2.0);
                }
            }
        }

        // --- 2. NEGATIVE CUTOUTS ---

        // 1. USB-C Port Notch (Bottom half at split line)
        translate([outer_w/2 - usbc_w/2, -1, back_depth - usbc_h/2])
            cube([usbc_w, wall_thick + 2, usbc_h + 1]);

        // 2. Wall Mounting Keyhole Top
        translate([outer_w/2, outer_l - 22.0, -1]) {
            cylinder(d=8.0, h=wall_thick + 2); // Head entry
            translate([-2.1, 0, 0]) cube([4.2, 9.0, wall_thick + 2]); // Shank slot
        }

        // 3. Wall Mounting Keyhole Bottom
        translate([outer_w/2, 22.0, -1]) {
            cylinder(d=8.0, h=wall_thick + 2);
            translate([-2.1, 0, 0]) cube([4.2, 9.0, wall_thick + 2]);
        }
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

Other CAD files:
docs/cad/doorbell_back_ascii.stl
docs/cad/doorbell_front.stl
docs/cad/doorbell_button.stl
docs/cad/doorbell_front.scad

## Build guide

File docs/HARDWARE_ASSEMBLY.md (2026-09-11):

# DoorCam Hardware Assembly & Soldering Blueprint

This document provides the complete, hole-by-hole assembly guide for soldering the **DoorCam Smart Video Doorbell** onto a standard **5cm x 7cm Double-Sided FR-4 Perfboard (Zero PCB)**.

---

## Components Checklist

| Component | Quantity | Position on Board |
|---|:---:|---|
| **5x7 cm FR-4 Double-Sided Perfboard** | 1 | Main substrate |
| **40-pin Female Header Strip** | Snip two 1x8 strips | Center-top (ESP32-CAM socket) |
| **Type-C 16-Pin Breakout Board** | 1 | Bottom edge (facing outward) |
| **SPST Tactile Push Button** | 1 | Bottom center / offset |
| **3-Pin Male Header Strip** | Snip 1x3 pins | Top/side edge (PIR harness connector) |
| **100uF 35V Electrolytic Capacitor** | 1 | Near ESP32-CAM 5V/GND pins |
| **100nF (104) Ceramic Capacitor** | 1 | In parallel with 100uF cap across 5V/GND |
| **24 AWG Hookup Wire** | A few scraps | Underside point-to-point bridging |

---

## Top-Side Component Layout

A 5x7 cm perfboard has **18 holes horizontally** and **28 holes vertically** (standard 2.54mm pitch).

`
   +---------------------------------------------------+
   |  [O] M3 Mounting Hole         M3 Mounting Hole [O]|  <-- TOP
   |                                                   |
   |              [PIR HEADER: VCC OUT GND]             |  <-- Row 4
   |                     (1x3 Male)                    |
   |                                                   |
   |      [ 1x8 Female ]         [ 1x8 Female ]        |  <-- Rows 7-14
   |      (ESP32-CAM Left)       (ESP32-CAM Right)     |      (Spaced 8 holes apart)
   |       1. 5V                  1. GND               |
   |       2. GND                 2. IO0               |
   |       3. IO12                3. IO16              |
   |       4. IO13 (PIR)          4. IO14 (Button)     |
   |       5. IO15                5. GND               |
   |       6. IO2                 6. 3V3               |
   |       7. IO4 (Flash)         7. U0R               |
   |       8. GND                 8. U0T               |
   |                                                   |
   |        [CAP: 100uF]  [CAP: 100nF]                 |  <-- Rows 16-17
   |                                                   |
   |                   [PUSH BUTTON]                   |  <-- Rows 19-21
   |                   (4-pin Tactile)                 |
   |                                                   |
   |             [TYPE-C BREAKOUT BOARD]               |  <-- Rows 24-27
   |                [ USB-C PORT v ]                   |  <-- BOTTOM EDGE
   |  [O] M3 Mounting Hole         M3 Mounting Hole [O]|
   +---------------------------------------------------+
`

---

## Circuit Schematic & Wiring Connections

### 1. Power Distribution (5V & GND Rails)
`
[Type-C Breakout]
   VBUS (5V) ───────┬───────────────────> ESP32-CAM Pin 1 (5V)
                    ├───────────────────> PIR Sensor Header Pin 1 (VCC)
                    ├──────(+) [100uF]
                    └───────┤  [100nF]
   GND      ────────┬──────(-) [100uF]
                    ├───────┤  [100nF]
                    ├───────────────────> ESP32-CAM Pin 2 (GND)
                    ├───────────────────> PIR Sensor Header Pin 3 (GND)
                    └───────────────────> Push Button Leg 1 (GND)
`

### 2. Sensor & Button Signal Wiring
`
[PIR Motion Sensor]
   OUT (Signal) ────────────────────────> ESP32-CAM Pin 4 (GPIO 13)

[Doorbell Push Button]
   Button Leg 1 ────────────────────────> Ground (GND)
   Button Leg 2 ────────────────────────> ESP32-CAM Pin 12 (GPIO 14)
   (Note: GPIO 14 has internal software PULLUP enabled in firmware; no external resistor needed!)
`

### 3. Capacitor Orientation (Crucial!)
* **100uF Electrolytic Capacitor (Black cylinder):**
  * **Longer Leg = POSITIVE (+)** -> Connect to **5V Rail**.
  * **Shorter Leg / White Stripe = NEGATIVE (-)** -> Connect to **GND Rail**.
* **100nF Ceramic Capacitor (Yellow/orange bead 104):**
  * Non-polar. Solder directly across 5V and GND right next to the 100uF capacitor.

---

## Step-by-Step Soldering Sequence

Follow this order for the cleanest assembly:

### Step 1: Prepare the Sockets
1. Take your 40-pin female header strip.
2. Carefully snip off **two 8-pin pieces** using flush cutters.
3. Clean up the edges so they sit flush.

### Step 2: Solder the ESP32-CAM Socket
1. Push the two 8-pin female headers into the perfboard spaced **8 holes apart** (20.32 mm from center-to-center).
2. Insert your ESP32-CAM into the female headers temporarily **before soldering**. This keeps both rows perfectly parallel while you solder the pins on the underside!
3. Solder the corner pins first, verify alignment, then solder all remaining pins.
4. Unplug the ESP32-CAM and set it aside safely.

### Step 3: Solder the Power Capacitors
1. Place the 100nF ceramic capacitor and 100uF electrolytic capacitor close to the ESP32-CAM 5V and GND pins.
2. Double-check electrolytic polarity: **White stripe with minus signs (-) must go to GND!**

### Step 4: Solder the Push Button & PIR Header
1. Push the 4-pin tactile button into the board and bend its legs slightly on the back so it stays in place. Solder all 4 pins.
2. Snip a **3-pin piece** from your male header strip and solder it near the top of the board for the PIR sensor wire harness.

### Step 5: Solder the USB-C Breakout Board
1. Place the Type-C breakout board along the bottom edge so the metal USB-C port faces outward past the edge of the perfboard.
2. Solder male header pins or short solid-core wires from the VBUS and GND pads into the perfboard power rails.

### Step 6: Underside Point-to-Point Wiring
1. Route short insulated wire bridges (or create clean solder bridges) connecting:
   - **5V Rail:** Type-C VBUS -> Capacitors (+) -> ESP32 Pin 1 (5V) -> PIR Pin 1 (VCC).
   - **GND Rail:** Type-C GND -> Capacitors (-) -> ESP32 Pin 2 (GND) -> PIR Pin 3 (GND) -> Button Leg 1.
   - **PIR Signal:** PIR Pin 2 (OUT) -> ESP32 Pin 4 (GPIO 13).
   - **Button Signal:** Button Leg 2 -> ESP32 Pin 12 (GPIO 14).

---

## Pre-Power Safety Checklist (Do NOT Skip!)

Before plugging in your USB-C cable for the first time:

1. **Multimeter Continuity Check:**
   - Set multimeter to Continuity / Beep mode.
   - Place one probe on **5V** and the other on **GND**.
   - **It must NOT beep!** (If it beeps, you have a solder bridge short-circuit. Inspect and clean the underside pads).
2. **Polarity Check:**
   - Verify the 100uF capacitor white stripe is on Ground.
3. **Power Test (Without ESP32-CAM):**
   - Plug in your USB-C cable **without the ESP32-CAM installed**.
   - Measure DC Voltage with multimeter across the female header pins:
     - Pin 1 (5V) to Pin 2 (GND) should read **+4.9V to +5.2V**.
4. **Final Assembly:**
   - Unplug USB.
   - Seat the ESP32-CAM firmly into its sockets.
   - Plug in USB -> Watch the red status LED blink and verify live stream on your dashboard!

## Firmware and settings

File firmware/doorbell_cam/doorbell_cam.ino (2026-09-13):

/*
 * Smart Video Doorbell - ESP32-CAM Firmware
 * Optimized for: ESP32-CAM (AI Thinker) with OV3660 Sensor & MB Programmer Shield
 * 
 * Hardware Connections:
 *   - PIR Motion Sensor (HC-SR501) OUT -> GPIO 13
 *   - Doorbell Push Button -> GPIO 14 (Connect other side of button to GND)
 *   - Flash LED -> GPIO 4 (Onboard high-power white LED)
 *   - Status LED -> GPIO 33 (Onboard small red LED, Active LOW)
 * 
 * Arduino IDE Settings:
 *   - Board: "AI Thinker ESP32-CAM"
 *   - CPU Frequency: 240MHz (WiFi/BT)
 *   - Flash Frequency: 80MHz
 *   - Flash Mode: QIO
 *   - Partition Scheme: "Huge APP (3MB No OTA/1MB SPIFFS)"
 *   - Upload Speed: 115200 or 921600
 */

#include "esp_camera.h"
#include <WiFi.h>
#include <WiFiClient.h>
#include <WiFiClientSecure.h>
#include "esp_http_server.h"
#include "soc/soc.h"
#include "soc/rtc_cntl_reg.h"

// Forward declarations
bool triggerDoorbell(const char* triggerType);
void streamCloudBurst(int durationSeconds);
bool checkCloudStreamCommand();

// ==========================================
// 1. NETWORK & SERVER CONFIGURATION
// ==========================================
#if __has_include("credentials.h")
  #include "credentials.h"
#else
  const char* ssid = "YOUR_WIFI_SSID";
  const char* password = "YOUR_WIFI_PASSWORD";
  const char* serverHost = "192.168.0.4"; // Local IP of server running doorbell_server.py
  const int serverPort = 5000;
#endif

#define ENABLE_PIR false  // Disabled temporarily to prevent false motion triggers
const char* serverPath = "/visitor";

// ==========================================
// 2. PIN DEFINITIONS (AI-THINKER PINOUT)
// ==========================================
#define PWDN_GPIO_NUM     32
#define RESET_GPIO_NUM    -1
#define XCLK_GPIO_NUM      0
#define SIOD_GPIO_NUM     26
#define SIOC_GPIO_NUM     27

#define Y9_GPIO_NUM       35
#define Y8_GPIO_NUM       34
#define Y7_GPIO_NUM       39
#define Y6_GPIO_NUM       36
#define Y5_GPIO_NUM       21
#define Y4_GPIO_NUM       19
#define Y3_GPIO_NUM       18
#define Y2_GPIO_NUM        5
#define VSYNC_GPIO_NUM    25
#define HREF_GPIO_NUM     23
#define PCLK_GPIO_NUM     22

// Peripherals
#define PIR_PIN           13     // HC-SR501 PIR Output (PULLDOWN prevents floating triggers)
#define BUTTON_PIN        14     // Doorbell Push Button (Active LOW with internal PULLUP)
#define FLASH_LED_PIN      4     // Onboard Flash LED (Active HIGH)
#define STATUS_LED_PIN    33     // Onboard Red LED (Active LOW)

// Hardware Button Interrupt State
volatile bool g_buttonTriggered = false;
unsigned long g_lastButtonInterruptTime = 0;

void IRAM_ATTR button_isr() {
  unsigned long now = millis();
  if (now - g_lastButtonInterruptTime > 300) {
    g_buttonTriggered = true;
    g_lastButtonInterruptTime = now;
  }
}

// Cooldown between captures to avoid spamming the server
const unsigned long CAPTURE_COOLDOWN_MS = 6000;
unsigned long lastCaptureTime = 0;
bool cameraInitialized = false;

// Global camera configuration structure
camera_config_t s_camera_config = {};

// HTTP server instance for live streaming
httpd_handle_t stream_httpd = NULL;

#define PART_BOUNDARY "123456789000000000000987654321"
static const char* _STREAM_CONTENT_TYPE = "multipart/x-mixed-replace;boundary=" PART_BOUNDARY;
static const char* _STREAM_BOUNDARY = "\r\n--" PART_BOUNDARY "\r\n";
static const char* _STREAM_PART = "Content-Type: image/jpeg\r\nContent-Length: %u\r\n\r\n";

// Stream handler for live video preview
static esp_err_t stream_handler(httpd_req_t *req) {
  camera_fb_t * fb = NULL;
  esp_err_t res = ESP_OK;
  size_t _jpg_buf_len = 0;
  uint8_t * _jpg_buf = NULL;
  char part_buf[64];

  res = httpd_resp_set_type(req, _STREAM_CONTENT_TYPE);
  if (res != ESP_OK) return res;

  httpd_resp_set_hdr(req, "Access-Control-Allow-Origin", "*");

  int consecutive_failures = 0;

  while (true) {
    fb = esp_camera_fb_get();
    if (!fb) {
      Serial.println("[CAM] Stream frame buffer grab failed");
      consecutive_failures++;
      if (consecutive_failures >= 15) {
        Serial.println("[CAM CRITICAL] 15 consecutive capture failures! Auto-restarting ESP32...");
        delay(100);
        ESP.restart();
      }
      delay(40);
      continue;
    }
    consecutive_failures = 0;

    _jpg_buf_len = fb->len;
    _jpg_buf = fb->buf;

    size_t hlen = snprintf((char *)part_buf, 64, _STREAM_PART, _jpg_buf_len);
    res = httpd_resp_send_chunk(req, (const char *)part_buf, hlen);
    if (res == ESP_OK) {
      res = httpd_resp_send_chunk(req, (const char *)_jpg_buf, _jpg_buf_len);
    }
    if (res == ESP_OK) {
      res = httpd_resp_send_chunk(req, _STREAM_BOUNDARY, strlen(_STREAM_BOUNDARY));
    }

    esp_camera_fb_return(fb);
    fb = NULL;
    _jpg_buf = NULL;

    // If client disconnected or socket send failed, exit cleanly
    if (res != ESP_OK) {
      break;
    }

    delay(10); // ~30 FPS with FreeRTOS CPU yield
  }
  return res;
}

void startCameraServer() {
  httpd_config_t config = HTTPD_DEFAULT_CONFIG();
  config.server_port = 81;
  config.ctrl_port = 32768;
  config.lru_purge_enable = true; // Auto-purge old/stale sockets immediately
  config.send_wait_timeout = 2;   // Fast timeout prevents socket locks
  config.recv_wait_timeout = 2;
  config.stack_size = 8192;       // Prevent stack overflows in stream task

  httpd_uri_t stream_uri = {
    .uri       = "/",
    .method    = HTTP_GET,
    .handler   = stream_handler,
    .user_ctx  = NULL
  };

  if (httpd_start(&stream_httpd, &config) == ESP_OK) {
    httpd_register_uri_handler(stream_httpd, &stream_uri);
    Serial.printf("[HTTP] Live MJPEG Stream available at http://%s:81/\n", WiFi.localIP().toString().c_str());
  }
}

// 15-20 FPS Live Cloud Stream Burst (Option C: 30-second stream on ring, or on-demand)
void streamCloudBurst(int durationSeconds) {
  Serial.printf("\n[STREAM] Starting %d-second live cloud stream to %s...\n", durationSeconds, serverHost);

  bool isHttps = (serverPort == 443);
  WiFiClient plainClient;
  WiFiClientSecure secureClient;
  WiFiClient *clientPtr = nullptr;

  if (isHttps) {
    secureClient.setInsecure();
    secureClient.setTimeout(2500);
    clientPtr = &secureClient;
  } else {
    plainClient.setTimeout(2000);
    clientPtr = &plainClient;
  }

  if (!clientPtr->connect(serverHost, serverPort)) {
    Serial.println("[STREAM WARN] Could not connect to cloud stream endpoint.");
    return;
  }

  unsigned long startTime = millis();
  unsigned long durationMs = (unsigned long)durationSeconds * 1000UL;
  int framesSent = 0;
  bool stopRequested = false;

  while ((millis() - startTime < durationMs) && !stopRequested) {
    // Check if Doorbell Button was pressed while streaming!
    if (digitalRead(BUTTON_PIN) == LOW) {
      delay(30);
      if (digitalRead(BUTTON_PIN) == LOW) {
        Serial.println("[STREAM] Button pressed during live stream! Logging visitor alert...");
        while (digitalRead(BUTTON_PIN) == LOW) { delay(10); }
        clientPtr->stop();
        triggerDoorbell("BUTTON");
        return; // triggerDoorbell initiates its own 30s stream burst
      }
    }

    if (!clientPtr->connected()) {
      if (!clientPtr->connect(serverHost, serverPort)) {
        delay(60);
        continue;
      }
    }

    camera_fb_t * fb = esp_camera_fb_get();
    if (!fb) {
      delay(20);
      continue;
    }

    // Push frame with exact Content-Length so proxy accepts it cleanly
    clientPtr->print(String("POST /api/frame_push HTTP/1.1\r\n") +
                     "Host: " + String(serverHost) + "\r\n" +
                     "Content-Type: image/jpeg\r\n" +
                     "Content-Length: " + String(fb->len) + "\r\n" +
                     "Connection: keep-alive\r\n\r\n");
    clientPtr->write(fb->buf, fb->len);

    esp_camera_fb_return(fb);
    framesSent++;

    // Fast non-blocking read of server response with STOP detection
    while (clientPtr->available() > 0) {
      char c = (char)clientPtr->read();
      if (c == 'S') {
        char sBuf[5] = {0};
        sBuf[0] = 'S';
        int r = 1;
        while (clientPtr->available() > 0 && r < 4) {
          sBuf[r++] = (char)clientPtr->read();
        }
        if (strncmp(sBuf, "STOP", 4) == 0) {
          Serial.println("[STREAM] Server signaled STOP (user ended session).");
          stopRequested = true;
          break;
        }
      }
    }

    // Blink status LED every 8 frames for live activity feedback
    if (framesSent % 8 == 0) {
      digitalWrite(STATUS_LED_PIN, !digitalRead(STATUS_LED_PIN));
    }

    delay(15); // Smooth 15-20 FPS rate without freezing
  }

  clientPtr->stop();
  digitalWrite(STATUS_LED_PIN, HIGH); // OFF

  unsigned long totalMs = millis() - startTime;
  float fps = (totalMs > 0) ? ((float)framesSent / (totalMs / 1000.0f)) : 0;
  Serial.printf("[STREAM COMPLETE] Sent %d frames in %.1fs (average %.1f FPS). Standby armed.\n", 
                framesSent, totalMs / 1000.0f, fps);
}

// Direct JPEG snapshot push to server (supports both local PC and Cloud/AWS servers!)
bool triggerDoorbell(const char* triggerType) {
  Serial.printf("\n[EVENT] Doorbell triggered by: %s!\n", triggerType);

  // Quick blink on status LED for immediate feedback
  digitalWrite(STATUS_LED_PIN, LOW); // ON (Active LOW)

  // Grab fresh high-res snapshot directly from camera sensor
  camera_fb_t * fb = esp_camera_fb_get();
  if (!fb) {
    Serial.println("[CAM ERROR] Failed to capture frame for upload!");
    digitalWrite(STATUS_LED_PIN, HIGH);
    return false;
  }

  bool isHttps = (serverPort == 443);
  WiFiClient plainClient;
  WiFiClientSecure secureClient;
  WiFiClient *clientPtr = nullptr;

  if (isHttps) {
    secureClient.setInsecure(); // Skip TLS cert validation for ultra-fast connection
    secureClient.setTimeout(3500);
    clientPtr = &secureClient;
  } else {
    plainClient.setTimeout(2500);
    clientPtr = &plainClient;
  }

  if (clientPtr->connect(serverHost, serverPort)) {
    String url = String(serverPath) + "?trigger=" + String(triggerType);
    clientPtr->print(String("POST ") + url + " HTTP/1.1\r\n" +
                     "Host: " + String(serverHost) + "\r\n" +
                     "Content-Type: image/jpeg\r\n" +
                     "Content-Length: " + String(fb->len) + "\r\n" +
                     "Connection: close\r\n\r\n");

    // Stream the binary JPEG bytes directly to server
    clientPtr->write(fb->buf, fb->len);

    // Brief check for acknowledgment
    unsigned long start = millis();
    while (clientPtr->connected() && millis() - start < 1500) {
      if (clientPtr->available()) {
        String line = clientPtr->readStringUntil('\n');
        if (line.indexOf("200") >= 0) {
          Serial.println("[SERVER] Doorbell event & photo acknowledged (200 OK)!");
          break;
        }
      }
    }
    clientPtr->stop();
  } else {
    Serial.printf("[WARN] Could not connect to %s:%d for trigger event.\n", serverHost, serverPort);
  }

  esp_camera_fb_return(fb);
  digitalWrite(STATUS_LED_PIN, HIGH); // OFF

  // Option C: If button pressed, stream live video to cloud for 30 seconds at 15-20 FPS!
  if (strcmp(triggerType, "BUTTON") == 0) {
    streamCloudBurst(30);
  }

  return true;
}


void setup() {
  WRITE_PERI_REG(RTC_CNTL_BROWN_OUT_REG, 0); // Disable brownout detector for stable streaming
  Serial.begin(115200);
  Serial.println("\n--- Starting Smart Video Doorbell (OV3660) ---");

  // Setup I/O pins
  pinMode(PIR_PIN, INPUT_PULLDOWN);
  pinMode(BUTTON_PIN, INPUT_PULLUP);
  pinMode(FLASH_LED_PIN, OUTPUT);
  pinMode(STATUS_LED_PIN, OUTPUT);
  digitalWrite(FLASH_LED_PIN, LOW);
  digitalWrite(STATUS_LED_PIN, HIGH); // Built-in LED is Active LOW

  // Hardware power-cycle camera sensor before configuration
  pinMode(PWDN_GPIO_NUM, OUTPUT);
  digitalWrite(PWDN_GPIO_NUM, HIGH); // Power OFF
  delay(150);
  digitalWrite(PWDN_GPIO_NUM, LOW);  // Power ON
  delay(150);

  // Configure Camera
  s_camera_config.ledc_channel = LEDC_CHANNEL_0;
  s_camera_config.ledc_timer = LEDC_TIMER_0;
  s_camera_config.pin_d0 = Y2_GPIO_NUM;
  s_camera_config.pin_d1 = Y3_GPIO_NUM;
  s_camera_config.pin_d2 = Y4_GPIO_NUM;
  s_camera_config.pin_d3 = Y5_GPIO_NUM;
  s_camera_config.pin_d4 = Y6_GPIO_NUM;
  s_camera_config.pin_d5 = Y7_GPIO_NUM;
  s_camera_config.pin_d6 = Y8_GPIO_NUM;
  s_camera_config.pin_d7 = Y9_GPIO_NUM;
  s_camera_config.pin_xclk = XCLK_GPIO_NUM;
  s_camera_config.pin_pclk = PCLK_GPIO_NUM;
  s_camera_config.pin_vsync = VSYNC_GPIO_NUM;
  s_camera_config.pin_href = HREF_GPIO_NUM;
  s_camera_config.pin_sccb_sda = SIOD_GPIO_NUM;
  s_camera_config.pin_sccb_scl = SIOC_GPIO_NUM;
  s_camera_config.pin_pwdn = PWDN_GPIO_NUM;
  s_camera_config.pin_reset = RESET_GPIO_NUM;
  s_camera_config.xclk_freq_hz = 16000000; // 16MHz for clean signal integrity and reliable I2C
  s_camera_config.pixel_format = PIXFORMAT_JPEG;
  s_camera_config.grab_mode = CAMERA_GRAB_LATEST;

  // PSRAM check and frame size configuration
  if (psramFound()) {
    Serial.println("[CAM] PSRAM detected! Using VGA 640x480 for rock-solid smooth streaming.");
    s_camera_config.frame_size = FRAMESIZE_VGA; // 640x480 (silky-smooth 25-30 FPS without WiFi congestion)
    s_camera_config.jpeg_quality = 16;          // High quality, fast transmission
    s_camera_config.fb_count = 2;
    s_camera_config.fb_location = CAMERA_FB_IN_PSRAM;
  } else {
    Serial.println("[CAM] Warning: PSRAM not detected. Lowering resolution to CIF.");
    s_camera_config.frame_size = FRAMESIZE_CIF;  // 400x296
    s_camera_config.jpeg_quality = 18;
    s_camera_config.fb_count = 1;
    s_camera_config.fb_location = CAMERA_FB_IN_DRAM;
  }

  // Camera Initialization with Automatic Retry
  esp_err_t err = ESP_FAIL;
  for (int attempt = 1; attempt <= 4; attempt++) {
    Serial.printf("[CAM] Initializing camera (attempt %d/4)...\n", attempt);
    err = esp_camera_init(&s_camera_config);
    if (err == ESP_OK) {
      break;
    }
    Serial.printf("[CAM] Attempt %d failed (0x%x). Power cycling sensor...\n", attempt, err);
    digitalWrite(PWDN_GPIO_NUM, HIGH);
    delay(200);
    digitalWrite(PWDN_GPIO_NUM, LOW);
    delay(200);
  }

  if (err != ESP_OK) {
    Serial.printf("\n[CAM ERROR] Camera init failed permanently with error 0x%x\n", err);
    if (err == 0x20001 || err == 0x105 || err == 0x106) {
      Serial.println("[CAM HINT] Camera sensor not detected over SCCB/I2C.");
      Serial.println("[CAM HINT] Check OV3660 ribbon cable: gold pins must face board, latch locked.");
    }
    cameraInitialized = false;
  } else {
    cameraInitialized = true;
    Serial.println("[CAM] Camera initialized successfully!");

    sensor_t * s = esp_camera_sensor_get();
    if (s && s->id.PID == OV3660_PID) {
      Serial.println("[CAM] OV3660 sensor detected. Applying image corrections...");
      s->set_vflip(s, 1);        // Correct upside-down orientation
      s->set_hmirror(s, 0);      // Horizontal mirror off
      s->set_brightness(s, 1);   // Slightly brighten picture
      s->set_saturation(s, -1);  // Slightly reduce harsh saturation
    } else if (s) {
      Serial.printf("[CAM] Sensor PID: 0x%x detected.\n", s->id.PID);
    }
  }

  // Connect to WiFi
  Serial.printf("[WIFI] Connecting to SSID: %s\n", ssid);
  WiFi.begin(ssid, password);
  while (WiFi.status() != WL_CONNECTED) {
    delay(500);
    Serial.print(".");
    digitalWrite(STATUS_LED_PIN, !digitalRead(STATUS_LED_PIN)); // Flash status LED while connecting
  }
  digitalWrite(STATUS_LED_PIN, HIGH); // Turn off after connecting

  Serial.println("\n[WIFI] Connected successfully!");
  WiFi.setSleep(false); // Ultra-low latency streaming without WiFi sleep pauses
  Serial.printf("[WIFI] Doorbell IP Address: http://%s\n", WiFi.localIP().toString().c_str());

  // Start live stream server on port 81
  startCameraServer();
  Serial.println("[SYS] Doorbell system armed and ready.");
}

// Check if cloud server is requesting an on-demand live stream
bool checkCloudStreamCommand() {
  if (WiFi.status() != WL_CONNECTED) {
    return false;
  }

  bool isHttps = (serverPort == 443);
  WiFiClient plainClient;
  WiFiClientSecure secureClient;
  WiFiClient *clientPtr = nullptr;

  if (isHttps) {
    secureClient.setInsecure();
    secureClient.setTimeout(1800);
    clientPtr = &secureClient;
  } else {
    plainClient.setTimeout(1500);
    clientPtr = &plainClient;
  }

  if (!clientPtr->connect(serverHost, serverPort)) {
    return false;
  }

  clientPtr->print(String("GET /api/stream_cmd HTTP/1.1\r\n") +
                   "Host: " + String(serverHost) + "\r\n" +
                   "Connection: close\r\n\r\n");

  unsigned long start = millis();
  String resp = "";
  while (clientPtr->connected() && millis() - start < 1200) {
    while (clientPtr->available()) {
      char c = clientPtr->read();
      resp += c;
    }
  }
  clientPtr->stop();

  if (resp.indexOf("\"stream\":true") >= 0 || resp.indexOf("\"stream\": true") >= 0) {
    return true;
  }
  return false;
}

void loop() {
  unsigned long now = millis();

  // 1. Check Doorbell Button (Active LOW) with hardware debounce filter
  if (digitalRead(BUTTON_PIN) == LOW) {
    delay(40); // Debounce delay
    if (digitalRead(BUTTON_PIN) == LOW) {
      if (now - lastCaptureTime > CAPTURE_COOLDOWN_MS) {
        lastCaptureTime = now;
        triggerDoorbell("BUTTON");
      }
      // Hold until button is released to prevent repeated triggers
      while (digitalRead(BUTTON_PIN) == LOW) {
        delay(20);
      }
    }
  }

#if ENABLE_PIR
  // 2. Check PIR Motion Sensor (Active HIGH)
  if (digitalRead(PIR_PIN) == HIGH) {
    if (now - lastCaptureTime > CAPTURE_COOLDOWN_MS) {
      lastCaptureTime = now;
      triggerDoorbell("PIR");
    }
  }
#endif

  // 3. Poll cloud server for on-demand live stream command every 1.5 seconds
  static unsigned long lastCmdCheck = 0;
  if (now - lastCmdCheck >= 1500) {
    lastCmdCheck = now;
    if (checkCloudStreamCommand()) {
      Serial.println("[CMD] Cloud requested On-Demand Live Stream! Starting 60s stream...");
      streamCloudBurst(60);
    }
  }

  delay(20);
}

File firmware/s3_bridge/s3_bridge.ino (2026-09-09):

/*
 * High-Speed USB-UART Bridge with Immediate USB Flush for ACKs
 */

#define CAM_RX 44  // S3 RX pin -> connected to CAM U0T
#define CAM_TX 43  // S3 TX pin -> connected to CAM U0R

HardwareSerial CamSerial(1);

void setup() {
  Serial.begin(115200);
  Serial.setRxBufferSize(4096);
  Serial.setTxBufferSize(4096);
  
  CamSerial.setRxBufferSize(4096);
  CamSerial.setTxBufferSize(4096);
  CamSerial.begin(115200, SERIAL_8N1, CAM_RX, CAM_TX);
}

void loop() {
  while (Serial.available()) {
    CamSerial.write(Serial.read());
  }
  
  if (CamSerial.available()) {
    while (CamSerial.available()) {
      Serial.write(CamSerial.read());
    }
    Serial.flush(); // Instantly push ACK packets to the PC!
  }
}

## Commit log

2026-09-09 feat(cad): Add parametric 3D printable doorbell enclosure in OpenSCAD with print guide
    [doorbell_case.scad]
2026-09-09 feat(firmware): Enable HC-SR501 PIR motion sensor detection on GPIO 13
2026-09-09 fix(ai): add CLAHE shadow enhancement, tilt fallback, and button-press settling delay
2026-09-11 docs(hardware): add complete perfboard component placement and soldering blueprint
2026-09-11 feat(cad): add Robu-ready watertight 3D printable STL files and renders for DoorCam enclosure
    [doorbell_back.scad, doorbell_back.stl, doorbell_back_ascii.stl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]
2026-09-11 feat(cad): optimize button mounting for 16mm metal waterproof panel button and 3D plunger
    [doorbell_back.stl, doorbell_back_ascii.stl, doorbell_button.scad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]
2026-09-11 fix(cad): re-export STLs through trimesh to eliminate false-positive normal warnings on slicer upload
    [doorbell_back.stl, doorbell_button.stl, doorbell_front.stl]
2026-09-12 Provide pkg_resources fallback and pin setuptools<70 for face_recognition_models
2026-09-12 Add Option C: 15-20 FPS cloud live streaming on ring with auto UI switching
2026-09-12 Push live frames directly to /api/frame_push with Content-Length for reliable cloud streaming
2026-09-13 Update ESP32 firmware with on-demand cloud streaming and smart flasher
2026-09-13 Add /api/latest_frame, instant connecting feedback, frame fallback, and no-cache headers
2026-09-13 Disable PIR motion sensor by default and add Motion toggle button on dashboard
2026-09-13 Fix JavaScript syntax error in alert string breaking all dashboard buttons
2026-09-13 Fix instant live stream stop and eliminate video freezing with non-blocking transmission
    [doorbell_cam.ino]
2026-09-13 Optimize livestream engine: event-driven frame broadcasting, GPU compositing, and Screen Wake Lock
2026-09-16 fix(cad): Align sensor apertures with soldered perfboard and R13-507 button
    [doorbell_back.stl, doorbell_back_ascii.stl, doorbell_button.stl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]
2026-09-16 fix(cad): Apply exact geometric math (cam_lens_y=62, pir_y=98, btn_y=28)
    [doorbell_back.stl, doorbell_back_ascii.stl, doorbell_button.stl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]
2026-09-16 fix(cad): Calibrate 3D case to exact user ruler measurements (130mm case, 46x66mm standoffs with locating pins)
    [doorbell_back.stl, doorbell_back_ascii.stl, doorbell_button.stl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]
2026-09-16 fix(cad): Align flash LED light-pipe to exact user measurement (2.6cm from board edge)
    [doorbell_back.stl, doorbell_back_ascii.stl, doorbell_button.stl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]
2026-09-16 fix(cad): Align camera lens (76.5mm) and flash LED (59.5mm) to Apsara ruler photo calibration
    [doorbell_back.stl, doorbell_back_ascii.stl, doorbell_button.stl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]
2026-09-16 fix(cad): Lock in exact physical eye-level ruler measurements (lens=73.5mm, led=52.0mm)
    [doorbell_back.stl, doorbell_back_ascii.stl, doorbell_button.stl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]
2026-09-16 fix(cad): Align flash LED light-pipe to bottom-right on front outside face (X=18.4mm)
    [doorbell_back.stl, doorbell_back_ascii.stl, doorbell_button.stl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]

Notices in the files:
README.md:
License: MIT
